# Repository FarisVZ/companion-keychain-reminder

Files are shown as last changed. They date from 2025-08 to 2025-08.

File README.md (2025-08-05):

# companion-keychain-reminder

a keychain to help poeple with disability that requires reminders every few hours, it also a little companion with oled display face that can be put on belt loop

# Work In Progress...

## Timeline

### June 22th 2025

**The first version on the project**
the first design was just a simple design to make a minimum req for esp12F to work and 3.3v regulator.

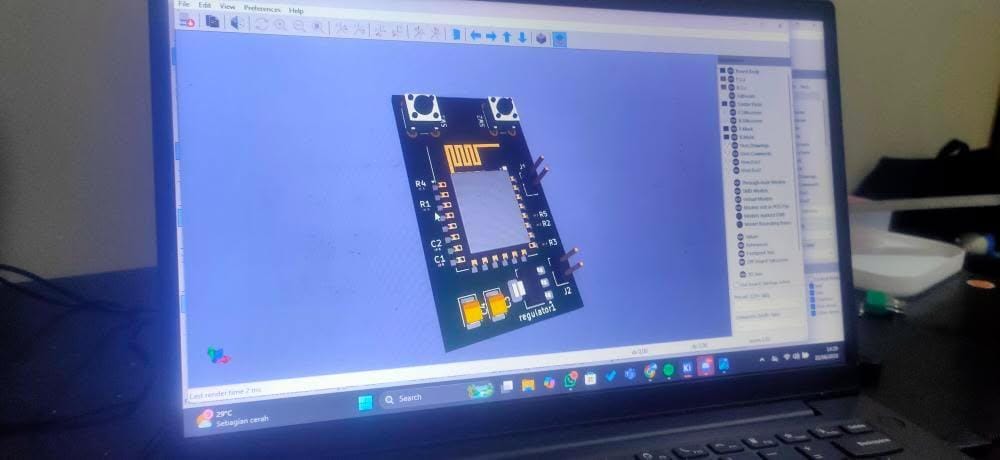
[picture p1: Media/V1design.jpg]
V1


### June 26th 2025

Changing some layout and adding more component to the board, that include:

- vibrator motor module
- oled display

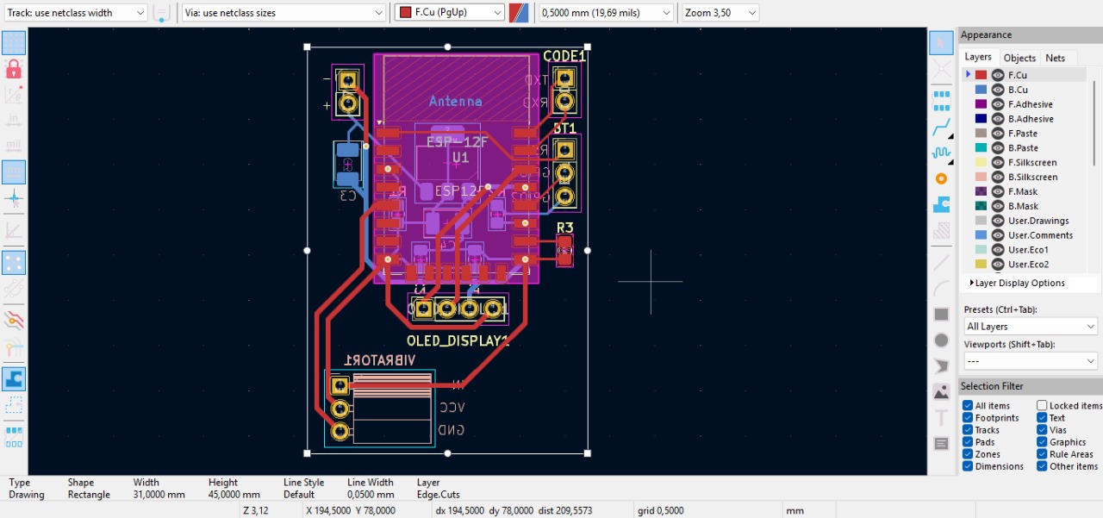
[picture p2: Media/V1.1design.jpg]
V1.1


### June 29th 2025

Adding 2 button for RST and Boot

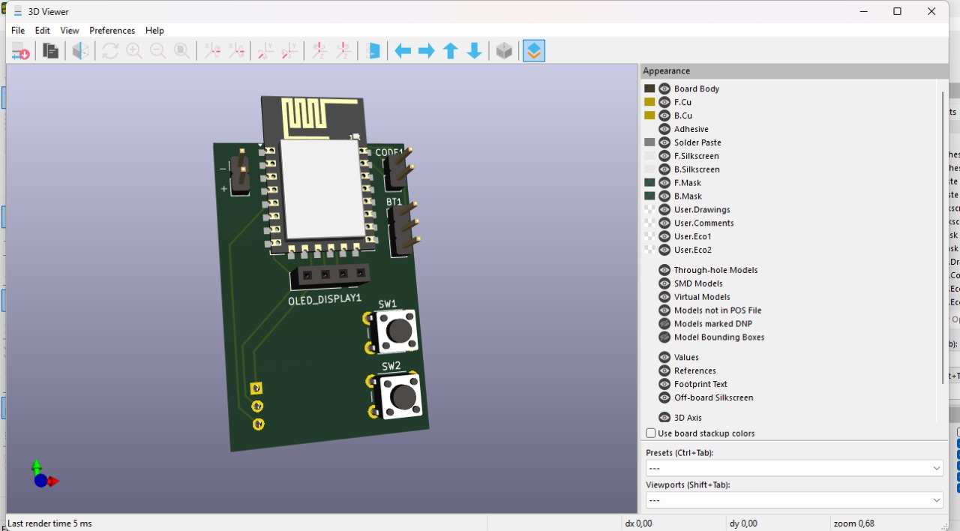
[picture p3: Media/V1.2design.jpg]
V1.2


### June 30th 2025

Trying to make version 2 by rerouting everything and uses bigger component

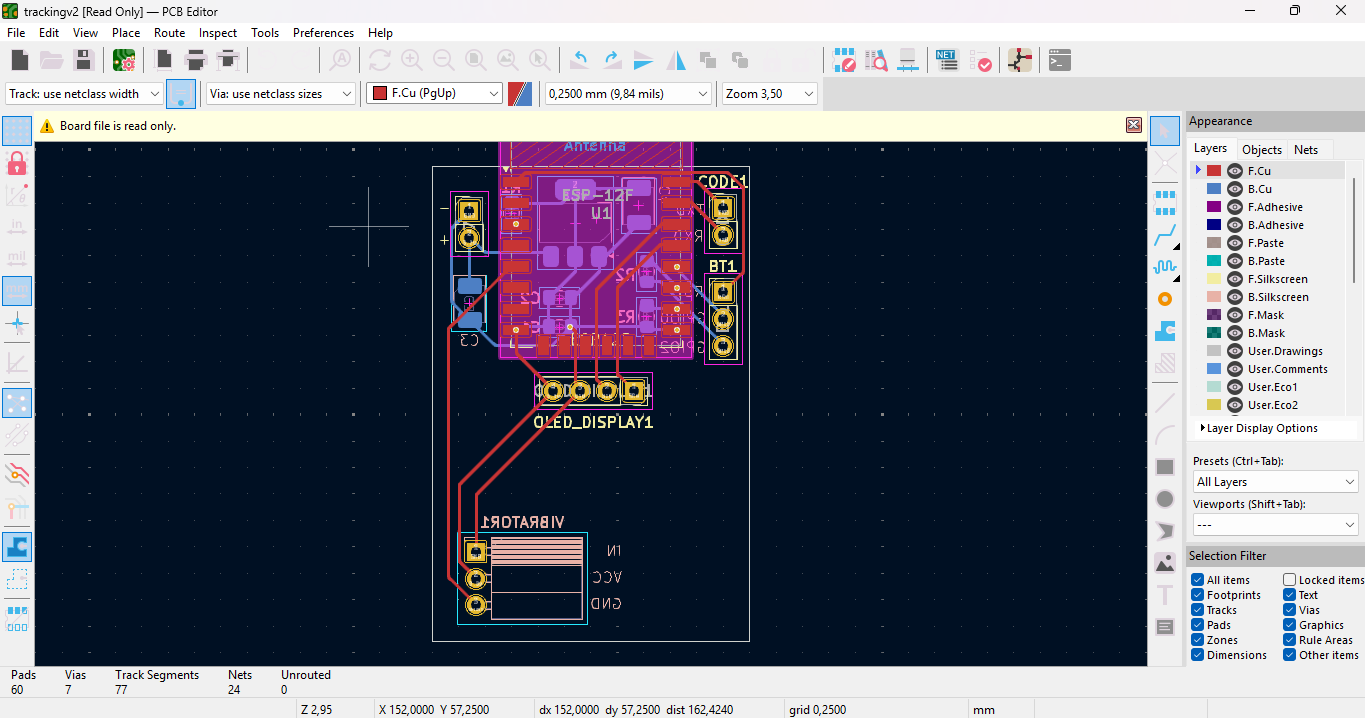
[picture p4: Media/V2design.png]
V2


### July 4th 2025

try to test it with real component and breadboard and find several issue:

- the module doesnt get enough current from the esp so it need a transistor
- only had few gpio to work with (3 for button, 1 for vibrator, and 2 for 12c address)

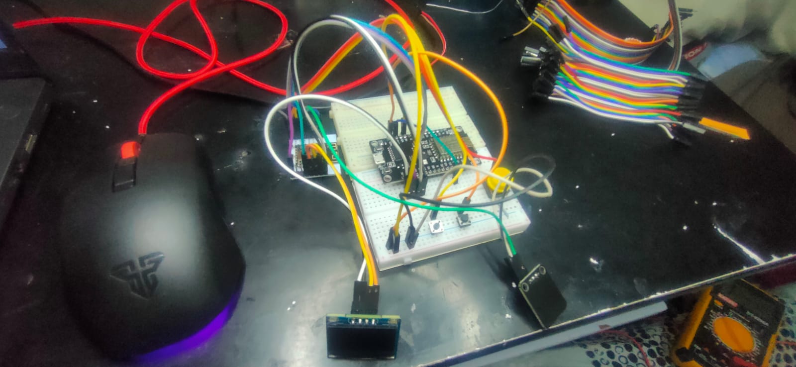
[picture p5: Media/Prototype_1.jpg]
Prototype_1


### July 5th 2025

trying the prototyping again to find another issue, by tweak something:

- adding a menu to oled display
- temporarily change to buzzer for the vibrator
- change into just two button for navigating up and down and implementing press both button to select menu

### July 8th 2025

- adding RTC to prototype
- adding 2n222 transistor so it can run the vibrator module
- go back use 3 button to navigating (up, down, select)
- add time in menu

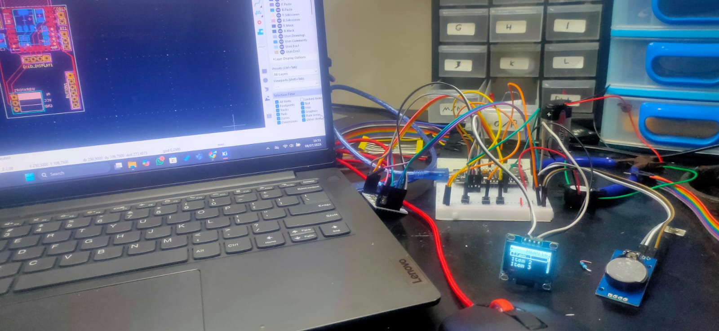
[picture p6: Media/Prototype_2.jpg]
Protype_2


### July 21th 2025

- adding pcf8574 ic into pcb to solve lack of gpio problem
- trying to just use ds3231 ic insted of module to make this project smaller
- adding 5 button to navigate

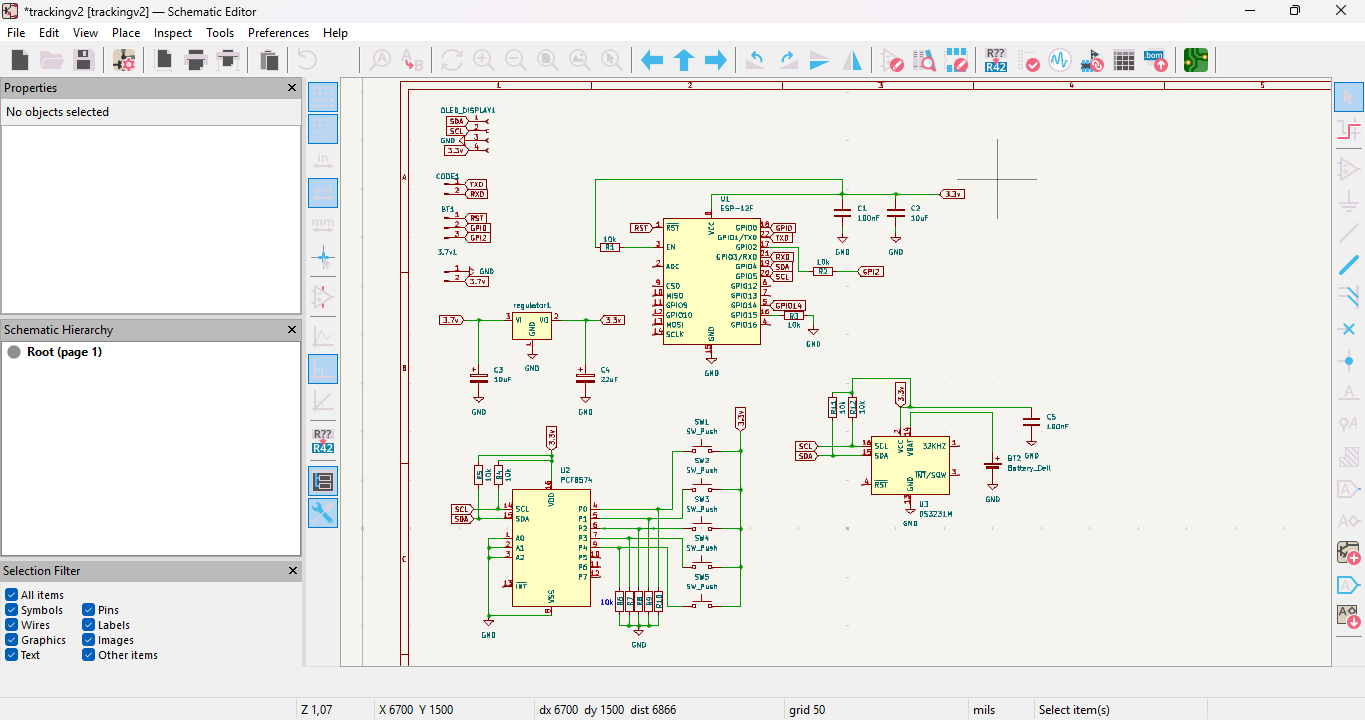
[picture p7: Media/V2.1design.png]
V2.1


### August 5th 2025

Making a github repo documentation about this project

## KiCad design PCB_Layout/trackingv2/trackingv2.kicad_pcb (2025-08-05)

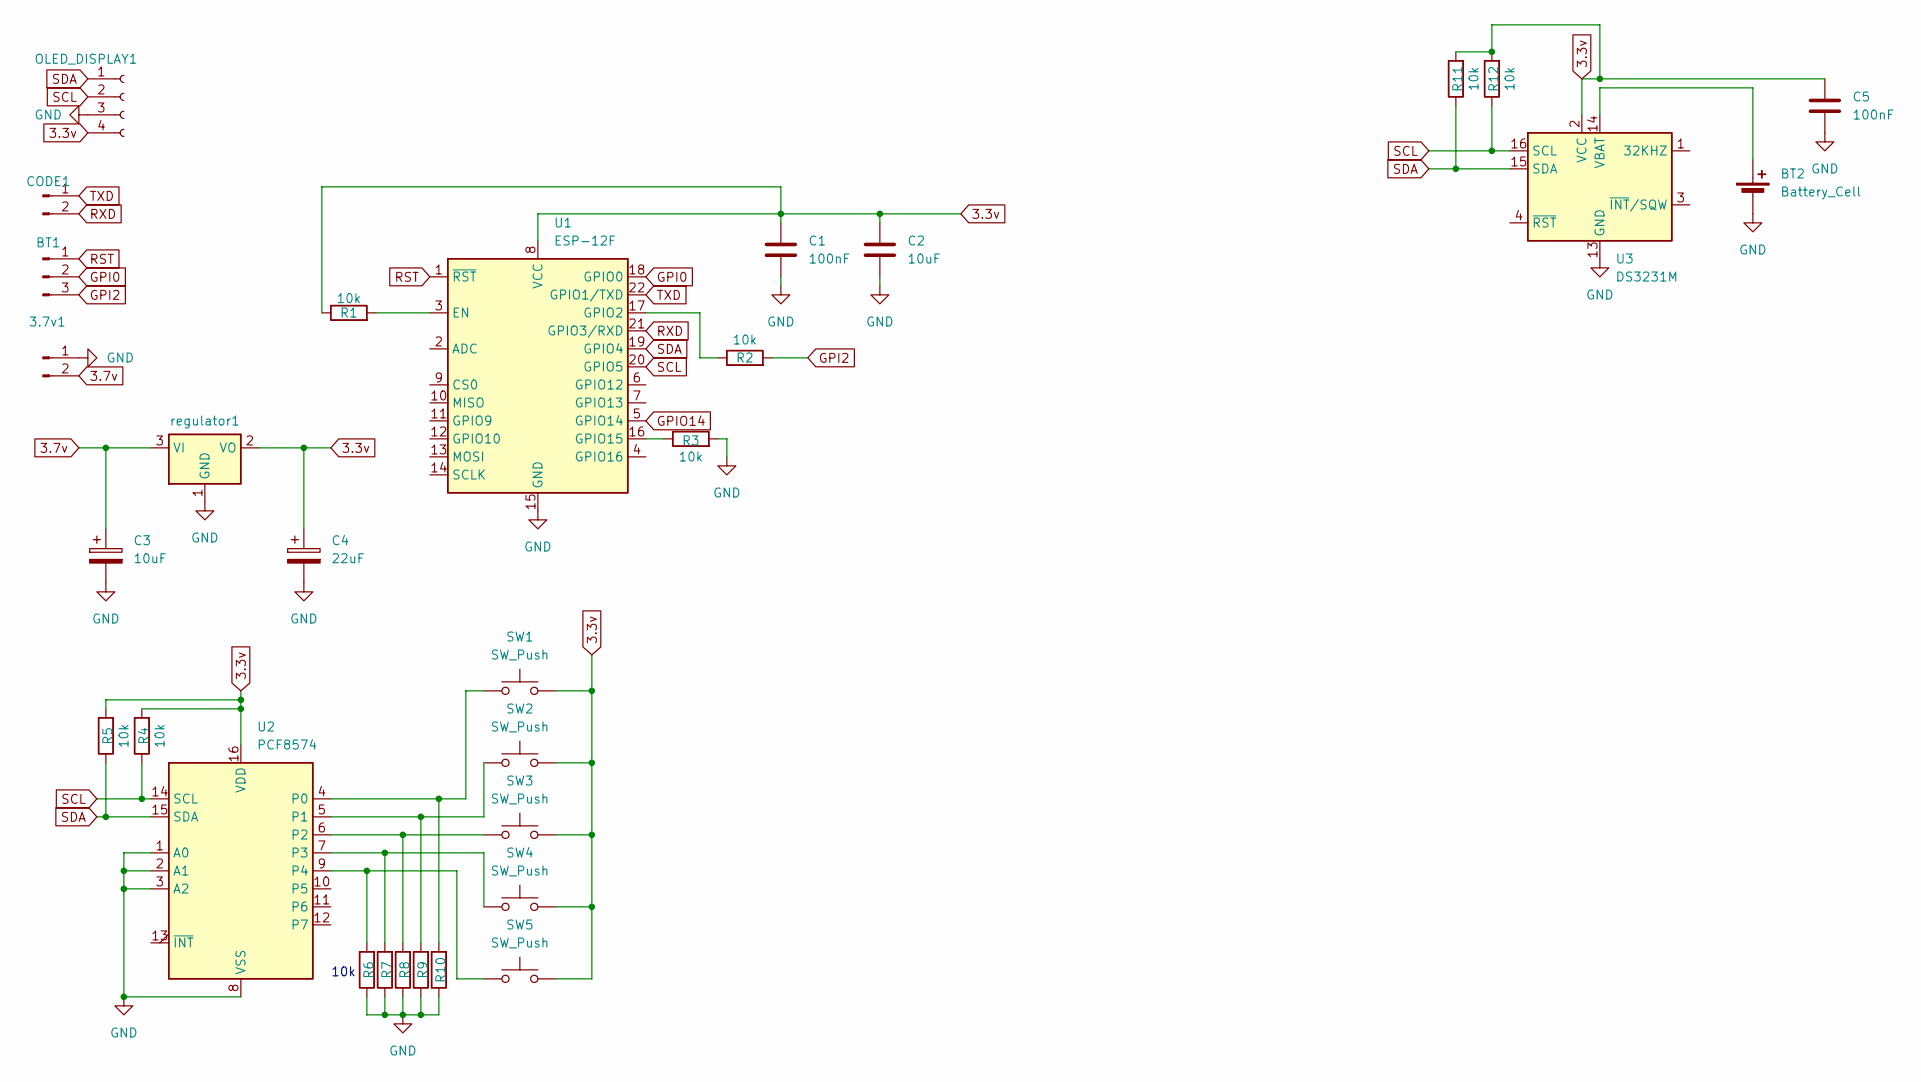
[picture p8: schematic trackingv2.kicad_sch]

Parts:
3.7v1: LiPo; PinHeader_1x02_P2.54mm_Vertical
BT1: Conn_01x03_Pin; PinHeader_1x03_P2.54mm_Vertical
BT2: Battery_Cell; BatteryHolder_Keystone_103_1x20mm
C1, C5: 100nF; C_0805_2012Metric_Pad1.18x1.45mm_HandSolder
C2: 10uF; C_0805_2012Metric_Pad1.18x1.45mm_HandSolder
C3: 10uF; CP_EIA-3528-15_AVX-H_Pad1.50x2.35mm_HandSolder
C4: 22uF; CP_EIA-3528-15_AVX-H_Pad1.50x2.35mm_HandSolder
CODE1: Conn_01x02_Pin; PinHeader_1x02_P2.54mm_Vertical
OLED_DISPLAY1: Conn_01x04_Socket; PinSocket_1x04_P2.54mm_Vertical
R1, R2, R3, R4, R5, R11, R12: 10k; R_0805_2012Metric_Pad1.20x1.40mm_HandSolder
R6, R7, R8, R9, R10: 10K; R_0805_2012Metric_Pad1.20x1.40mm_HandSolder
SW1, SW2, SW3, SW4, SW5: SW_Push; SW_PUSH_6mm
U1: ESP-12F; ESP-12E
U2: PCF8574; SOIC-16_3.9x9.9mm_P1.27mm
U3: DS3231M; SOIC-16W_7.5x10.3mm_P1.27mm
regulator1: SOT-223-3_TabPin2

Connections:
3.3v: C1.1, C2.1, C4.1, C5.1, OLED_DISPLAY1.4, R1.1, R4.2, R5.2, R11.2, R12.2, SW1.2, SW2.2, SW3.2, SW4.2, SW5.2, U1.8 (VCC), U2.16 (VDD), U3.2 (VCC), regulator1.2 (VO)
3.7v: 3.7v1.2, C3.1, regulator1.3 (VI)
GND: 3.7v1.1, BT2.2 (-), C1.2, C2.2, C3.2, C4.2, C5.2, OLED_DISPLAY1.3, R3.2, R6.1, R7.1, R8.1, R9.1, R10.1, U1.15 (GND), U2.1 (A0), U2.2 (A1), U2.3 (A2), U2.8 (VSS), U3.5 (GND), U3.6 (GND), U3.7 (GND), U3.8 (GND), U3.9 (GND), U3.10 (GND), U3.11 (GND), U3.12 (GND), U3.13 (GND), regulator1.1 (GND)
GPI0: BT1.2, U1.18 (GPIO0)
GPI2: BT1.3, R2.2
GPIO14: U1.5 (GPIO14)
unnamed: BT2.1 (+), U3.14 (VBAT)
unnamed: R1.2, U1.3 (EN)
unnamed: R2.1, U1.17 (GPIO2)
unnamed: R3.1, U1.16 (GPIO15)
unnamed: R10.2, SW1.1, U2.4 (P0)
unnamed: R9.2, SW2.1, U2.5 (P1)
unnamed: R8.2, SW3.1, U2.6 (P2)
unnamed: R7.2, SW4.1, U2.7 (P3)
unnamed: R6.2, SW5.1, U2.9 (P4)
RST: BT1.1, U1.1 (~RST)
RXD: CODE1.2, U1.21 (GPIO3/RXD)
SCL: OLED_DISPLAY1.2, R4.1, R12.1, U1.20 (GPIO5), U2.14 (SCL), U3.16 (SCL)
SDA: OLED_DISPLAY1.1, R5.1, R11.1, U1.19 (GPIO4), U2.15 (SDA), U3.15 (SDA)
TXD: CODE1.1, U1.22 (GPIO1/TXD)

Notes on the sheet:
10k

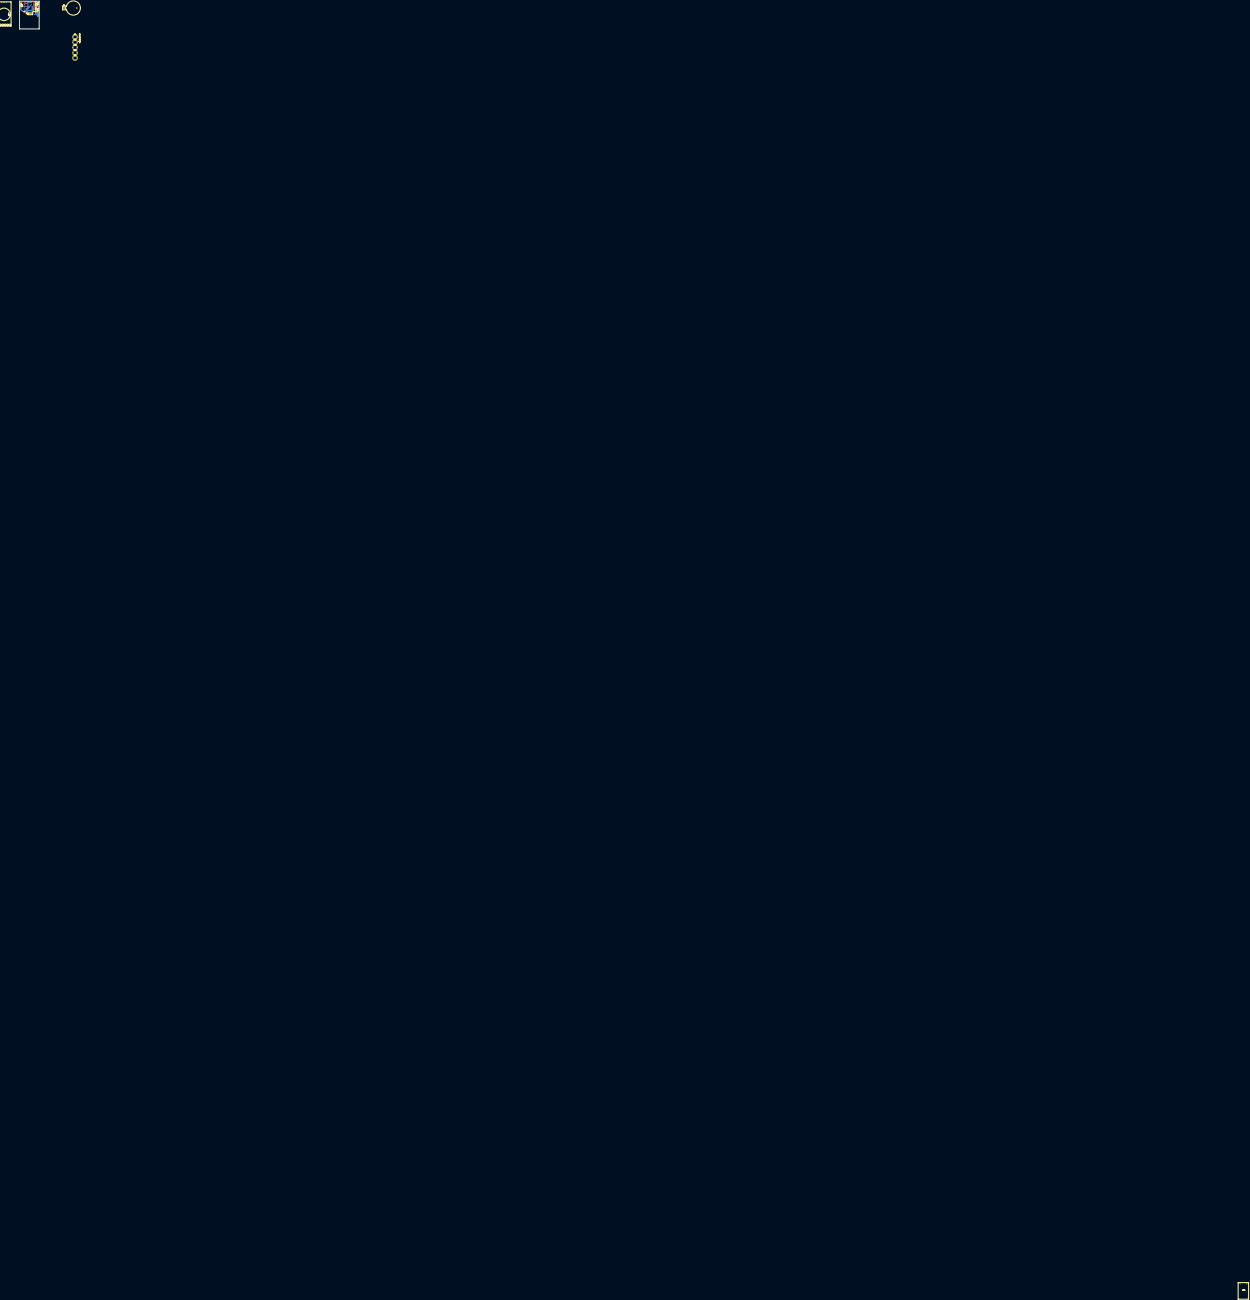
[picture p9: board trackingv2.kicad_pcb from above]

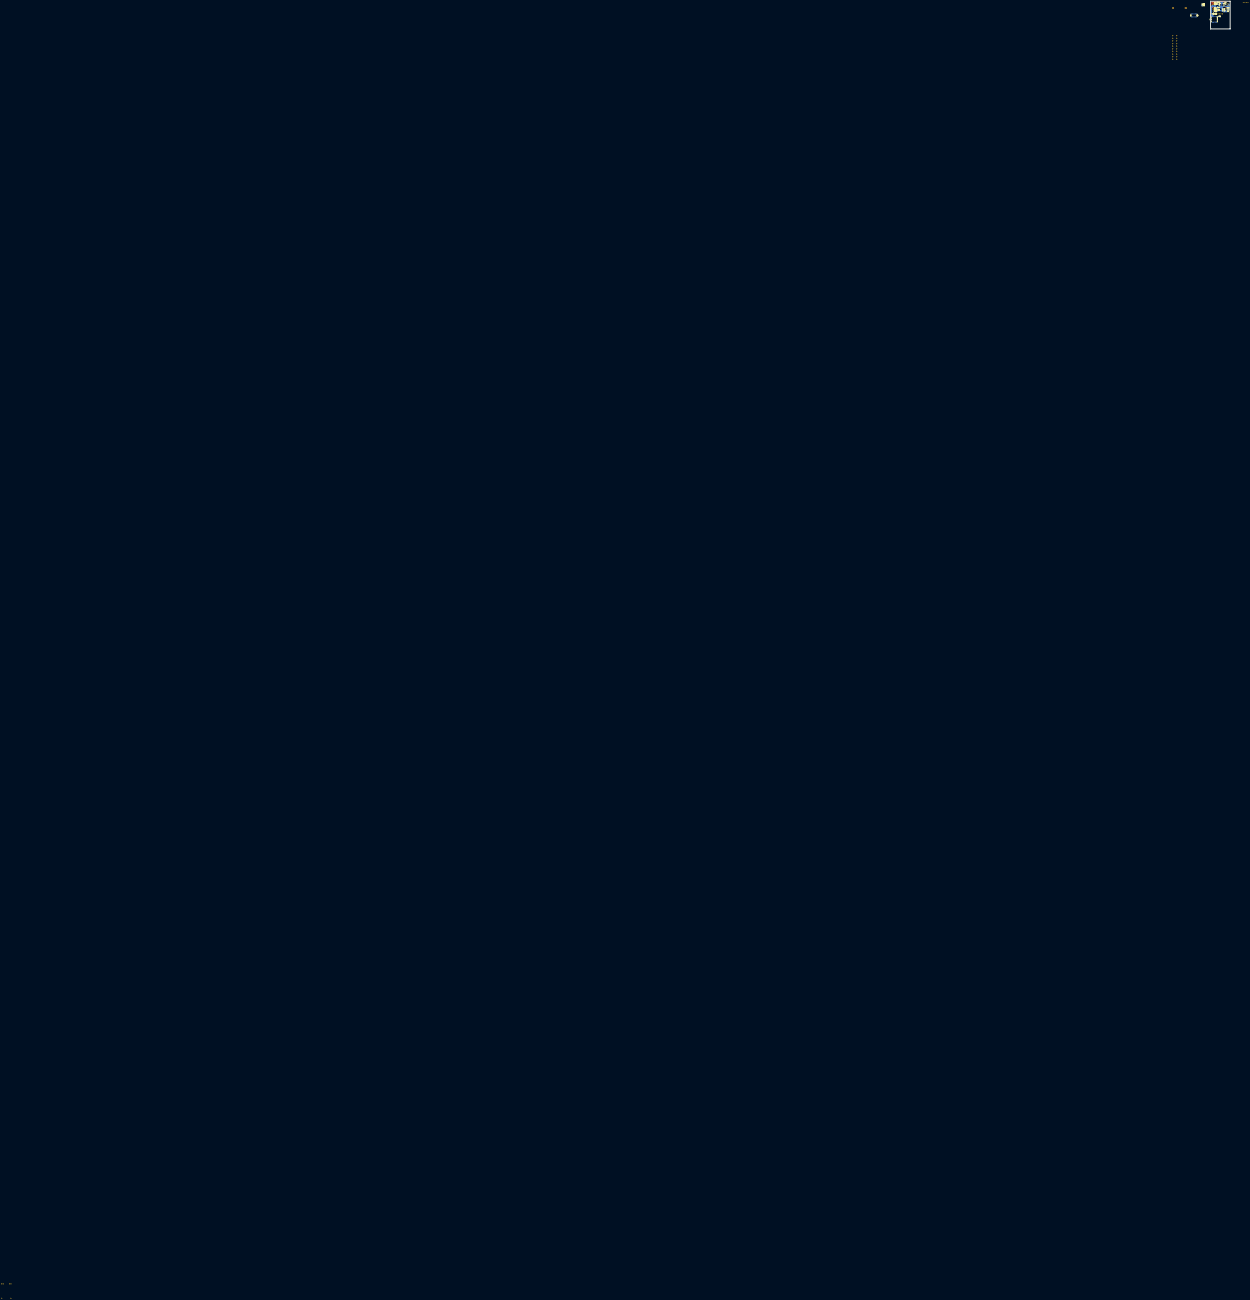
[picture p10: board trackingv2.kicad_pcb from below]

Board: 2 copper layers, 32.0 x 45.0 mm, 31 parts (15 on the bottom side), 19 nets.

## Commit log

2025-08-05 add pcb kicad layout
    [trackingv2-B_Cu.gbr, trackingv2-B_Mask.gbr, trackingv2-B_Paste.gbr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]
2025-08-05 adding july 21
    [trackingv2.kicad_sch]
